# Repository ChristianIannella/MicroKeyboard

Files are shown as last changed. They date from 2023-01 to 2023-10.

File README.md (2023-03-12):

# MicroKeyboard

MicroKeyboard is a small customizable keyboard/mouse.

Based on [ArduinoMicro](https://store.arduino.cc/products/arduino-micro), it allows you to choose the function to be associated with each single key, including encoder and thumbstick.

MicroKeyboard is open-source and open-hardware but you can still decide to buy one already assembled on [Tindie](https://www.tindie.com/products/chris_maker_/microkeyboard/)

<picture><picture>

Thanks to PCBWay for sponsoring this project.

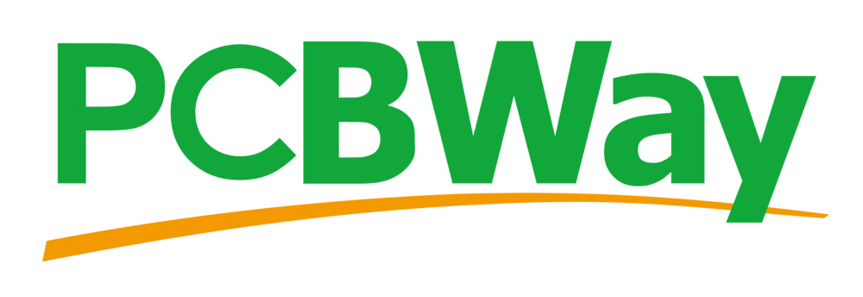
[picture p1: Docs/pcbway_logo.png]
PCBWay


[ITALIANO](https://github.com/ChristianIannella/MicroKeyboard/blob/main/ITALIANO.md)
  
[ENGLISH](https://github.com/ChristianIannella/MicroKeyboard/blob/main/ENGLISH.md)

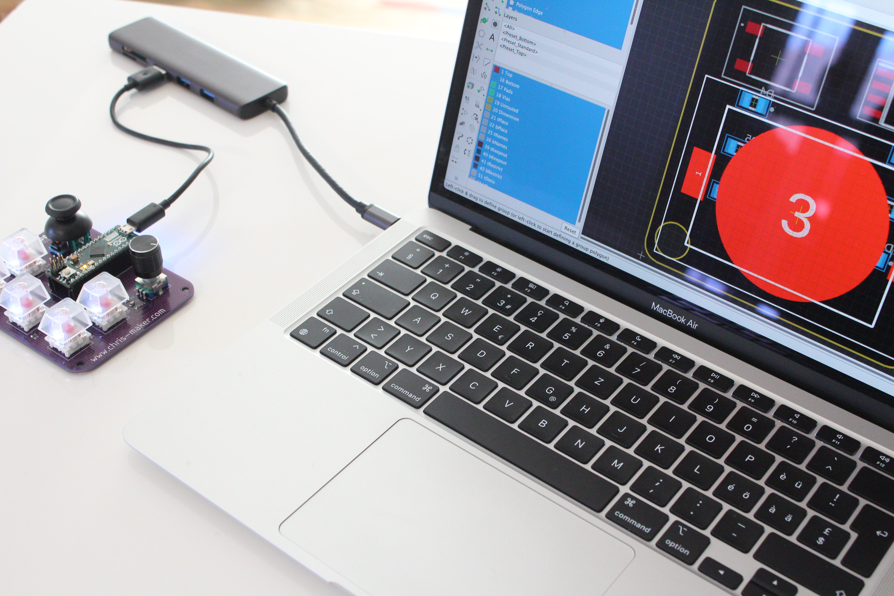
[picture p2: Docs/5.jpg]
MicroKeyboard


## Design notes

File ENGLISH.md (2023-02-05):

# MicroKeyboard

MicroKeyboard is a small customizable keyboard/mouse.

Based on [ArduinoMicro](https://store.arduino.cc/products/arduino-micro), it allows you to choose the function to be associated with each single key, including encoder and thumbstick.

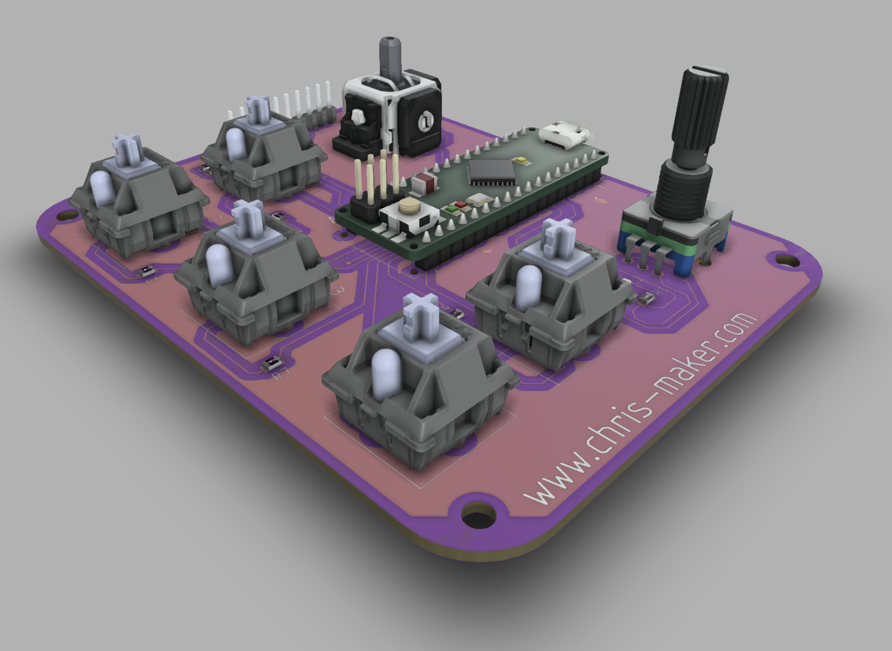
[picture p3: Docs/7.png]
MicroKeyboard


## PCB
  
On board the board you'll find a two-axis thumbstick with push button, a push button encoder, and five Cherry MX-style buttons. Each of the 5 buttons has a led connected to a `PWM` output of the micro in order to create an infinity of light effect.

Also you will find a connector with the remaining free pins of the micro including I2C and UART port.

The `SCL` and `SDA` pins are pulled-up from R8 and R9 (10k). If you want to interface a device via I2C or UART port that works at 3.3v you will need a level adapter.

Remember Arduino Micro works at 5v, if you decide to power the board from the external port remember that `VIN` must be between 7 and 12v!
  
For more details see [datasheet](https://store.arduino.cc/products/arduino-micro)

You can find Wiring diagram [here](https://github.com/ChristianIannella/MicroKeyboard/blob/main/Docs/Microkeyboard_schematic.png)  

## FIRMWARE  

There are some examples in the [Arduino](https://github.com/ChristianIannella/MicroKeyboard/tree/main/Arduino/Example_1) folder which you can use to inspire you to customize your MicroKeyboard.

You can choose from several [layout](https://github.com/ChristianIannella/MicroKeyboard/blob/main/Docs/Layout.txt)

Here is a list of all available functions [keycode](https://github.com/ChristianIannella/MicroKeyboard/blob/main/Docs/Keycode.txt)

In the examples two libraries are used, one for managing the encoder and one for simulating the mouse and keyboard.
  
  - [HID Project](https://github.com/NicoHood/HID) by [NicoHood](https://github.com/NicoHood)
  - [EncoderButton](https://github.com/Stutchbury/EncoderButton) by [Stutchbury](https://github.com/Stutchbury)
  
Visit these pages and you will discover how many things you can do with so few buttons.

In addition, it is possible to use the libraries made available by Arduino.cc

- [Keyboard](https://www.arduino.cc/reference/en/language/functions/usb/keyboard/)
- [Mouse](https://www.arduino.cc/reference/en/language/functions/usb/mouse/)

[BACK](https://github.com/ChristianIannella/MicroKeyboard)

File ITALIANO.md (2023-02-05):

# MicroKeyboard

MicroKeyboard è una piccola tastiera completamente customizzabile che in realtà racchiude anche un mouse.

Basata su [ArduinoMicro](https://store.arduino.cc/products/arduino-micro) permette di scegliere la funzione da associare ad ogni singolo tasto inclusi encoder e thumbstick.

MicroKeyboard

## PCB

A bordo della scheda troverai un thumbstick a due assi con pulsante, un encoder con pulsante e cinque pulsatti di tipo Cherry MX. Ognuno dei 5 pulsanti ha un led collegato a un uscita `PWM` del micro in modo da poter creare una infinità di giochi di luce.

Inoltre troverai un connettore con i rimanenti pin liberi del micro tra cui porta I2C e UART.
I pin `SCL` e `SDA` sono tenuti a pull-up da R8 e R9 (10k). Se vorrai interfacciare un dispositivo tramite porta I2C o UART che lavora a 3.3v avrai bisogno di un adattatore di livelli. 

Ricorda Arduino Micro lavora a 5v se invece decidi di alimentare la scheda dalla porta esterna ricorda che `VIN` deve essere compresa tra 7 e 12v!
  
Per maggiori dettagli consulta la scheda tecnica [qui](https://store.arduino.cc/products/arduino-micro)

Puoi trovare lo schema elettrico [qui](https://github.com/ChristianIannella/MicroKeyboard/blob/main/Docs/Microkeyboard_schematic.png)

## FIRMWARE  
  
Ci sono alcuni esempi nella cartella [Arduino](https://github.com/ChristianIannella/MicroKeyboard/tree/main/Arduino/Example_1) ai quali potrai ispirarti per customizzare la tua MicroKeyboard.  

E' possibile scegliere tra diversi [layout](https://github.com/ChristianIannella/MicroKeyboard/blob/main/Docs/Layout.txt) 

Ecco una lista di tutte le funzioni disponibili [keycode](https://github.com/ChristianIannella/MicroKeyboard/blob/main/Docs/Keycode.txt)
  
Negli esempi vengono utilizzate due librerie, una per la gestione dell'encoder e una per la simulazione di mouse e tastiera. 
  
  - [HID Project](https://github.com/NicoHood/HID) di [NicoHood](https://github.com/NicoHood)
  - [EncoderButton](https://github.com/Stutchbury/EncoderButton) di [Stutchbury](https://github.com/Stutchbury)
  
Visita queste pagine e scoprirai quante cose puoi fare con cosí pochi pulsanti.

In oltre è possibile sfruttare le librerie messe a disposizione da Arduino.cc 

- [Keyboard](https://www.arduino.cc/reference/en/language/functions/usb/keyboard/)
- [Mouse](https://www.arduino.cc/reference/en/language/functions/usb/mouse/)

[INDIETRO](https://github.com/ChristianIannella/MicroKeyboard)

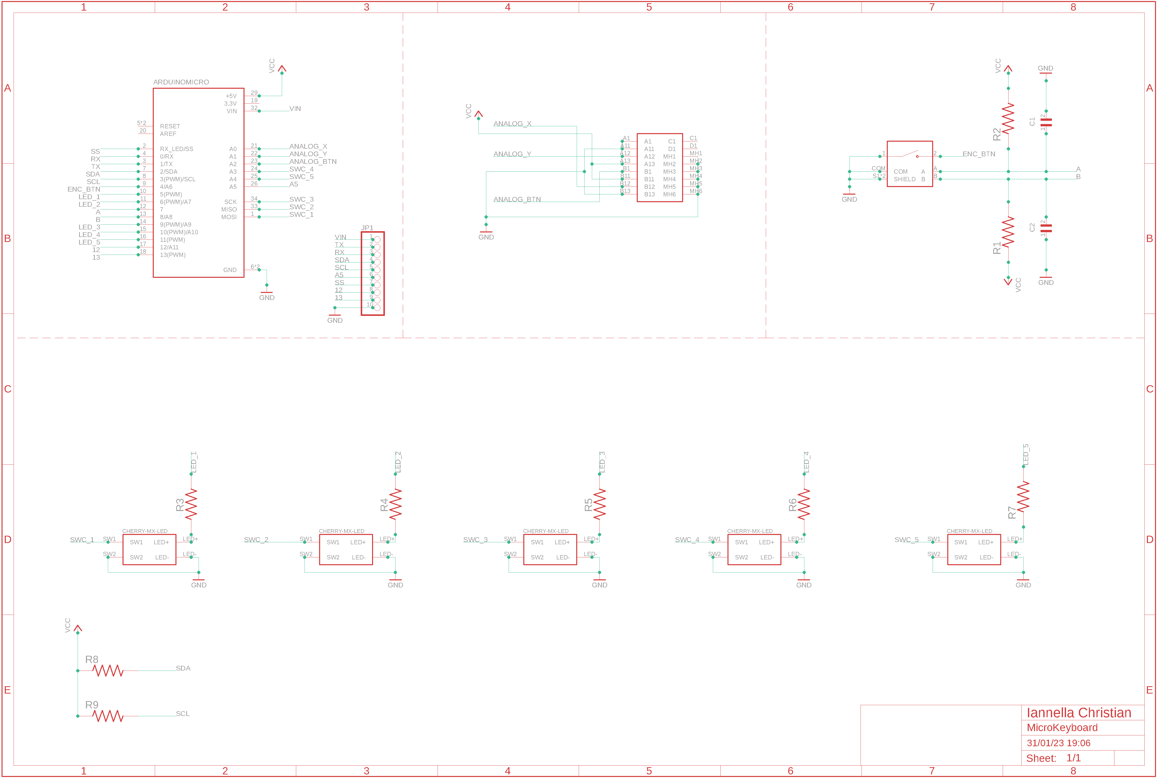
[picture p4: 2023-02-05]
Docs/Microkeyboard_schematic.png

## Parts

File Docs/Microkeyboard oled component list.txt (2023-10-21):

R1 1K
R2 1K
R3 1k
R4 1k
R6 4.7K
R7 4.7K
R8 10K
R9 10K

C1 0.01 uF
C2 0.01 uF

Display SSD1305 128x32

Pulsante Cherry MX

Led standard 3mm

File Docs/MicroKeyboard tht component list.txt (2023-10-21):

R1 1K
R2 1K
R3 1k
R4 1k
R5 1k
R6 4.7K
R7 4.7K
R8 10K
R9 10K

C1 0.01 uF
C2 0.01 uF

Pulsante Cherry MX
Led standard 3mm

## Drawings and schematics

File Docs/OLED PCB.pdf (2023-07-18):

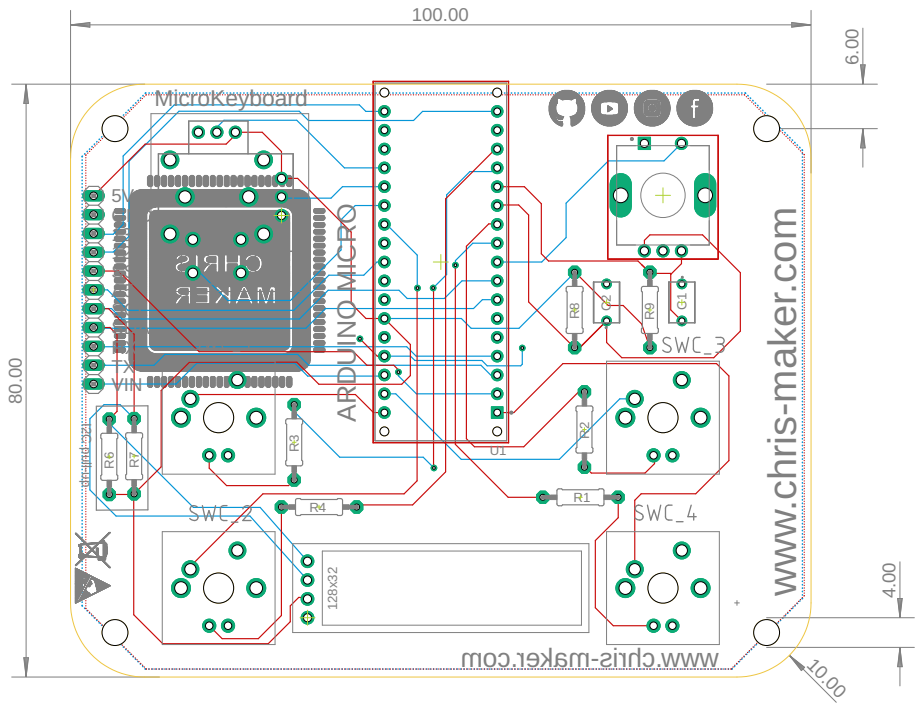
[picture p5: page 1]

moc.r eka m- sir hc. www ARDUINO MICRO w .chris-maker.com MicroKeyboard 128x32 80.00 100.00 10.04.00 6.00 GND 1312SSA5SCL SDA RXTXVIN I2C pull-up 5V S1 C2C1 R1R2 R3 R4 R6R7 R8 R9 U1

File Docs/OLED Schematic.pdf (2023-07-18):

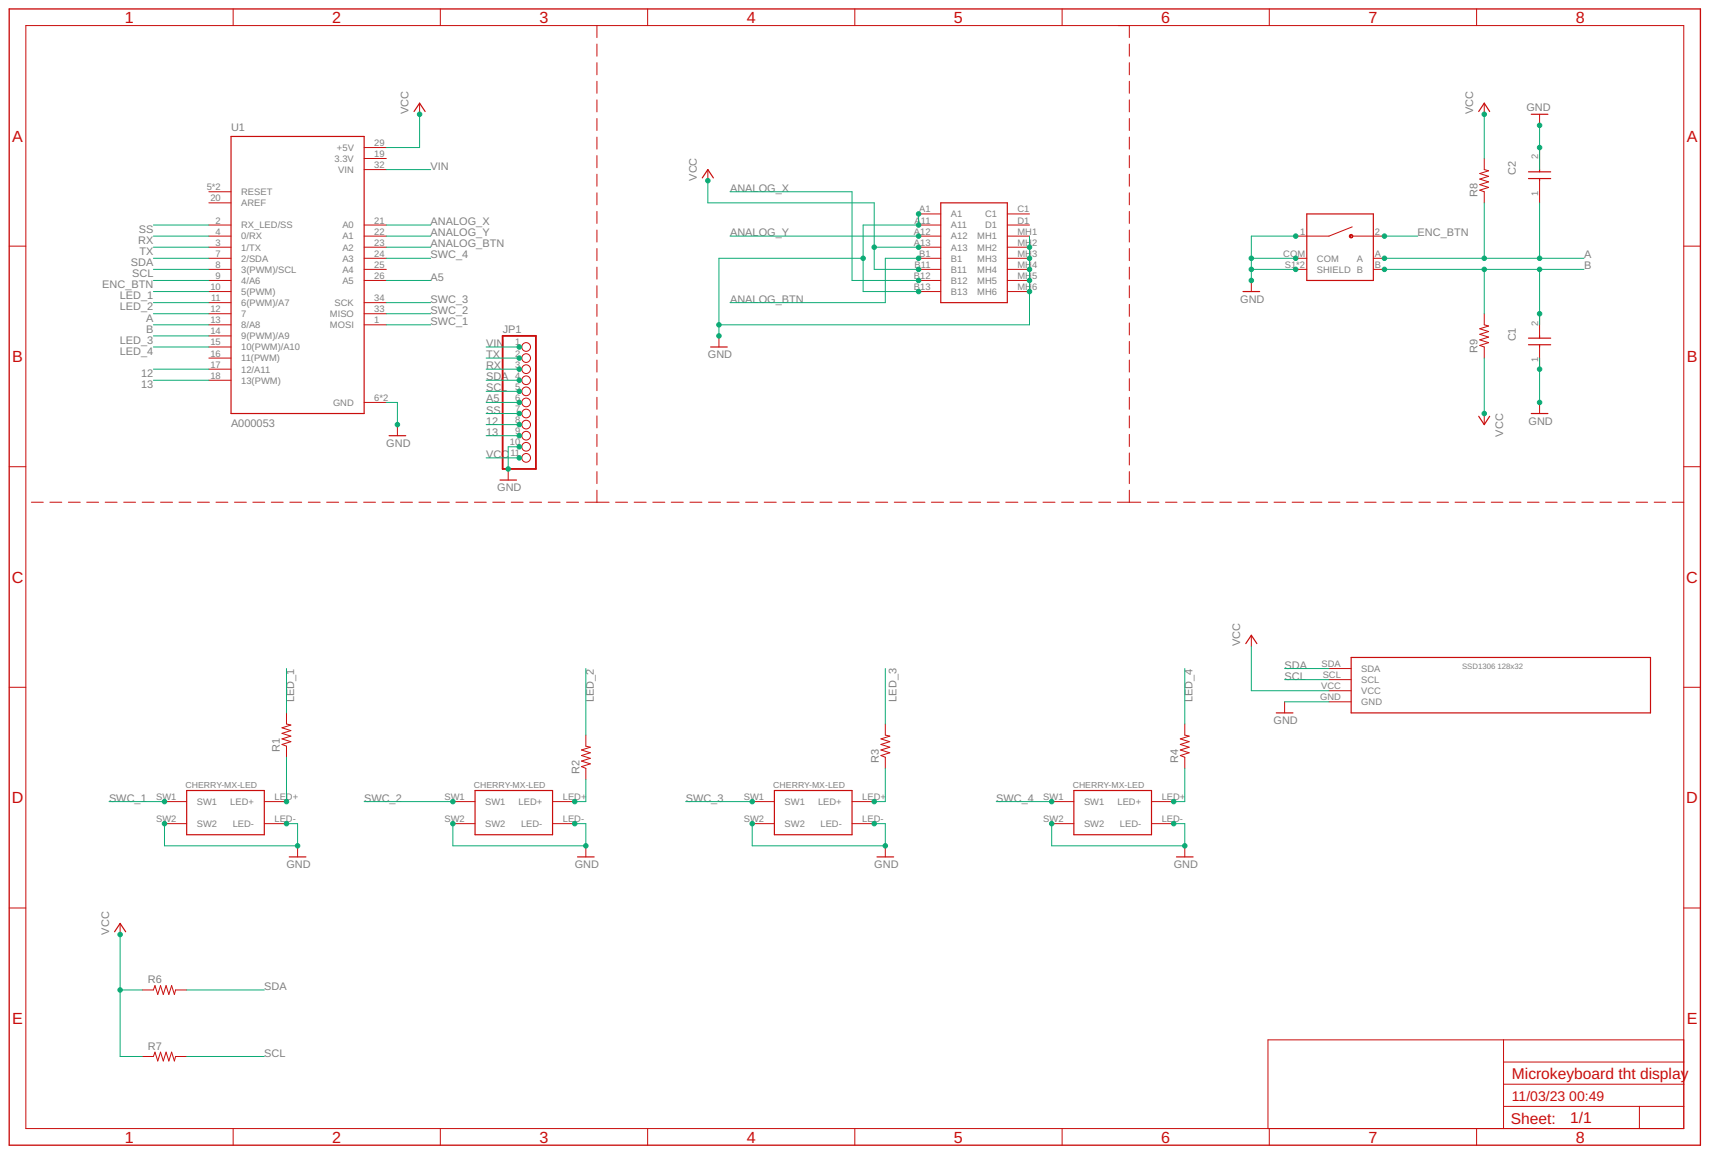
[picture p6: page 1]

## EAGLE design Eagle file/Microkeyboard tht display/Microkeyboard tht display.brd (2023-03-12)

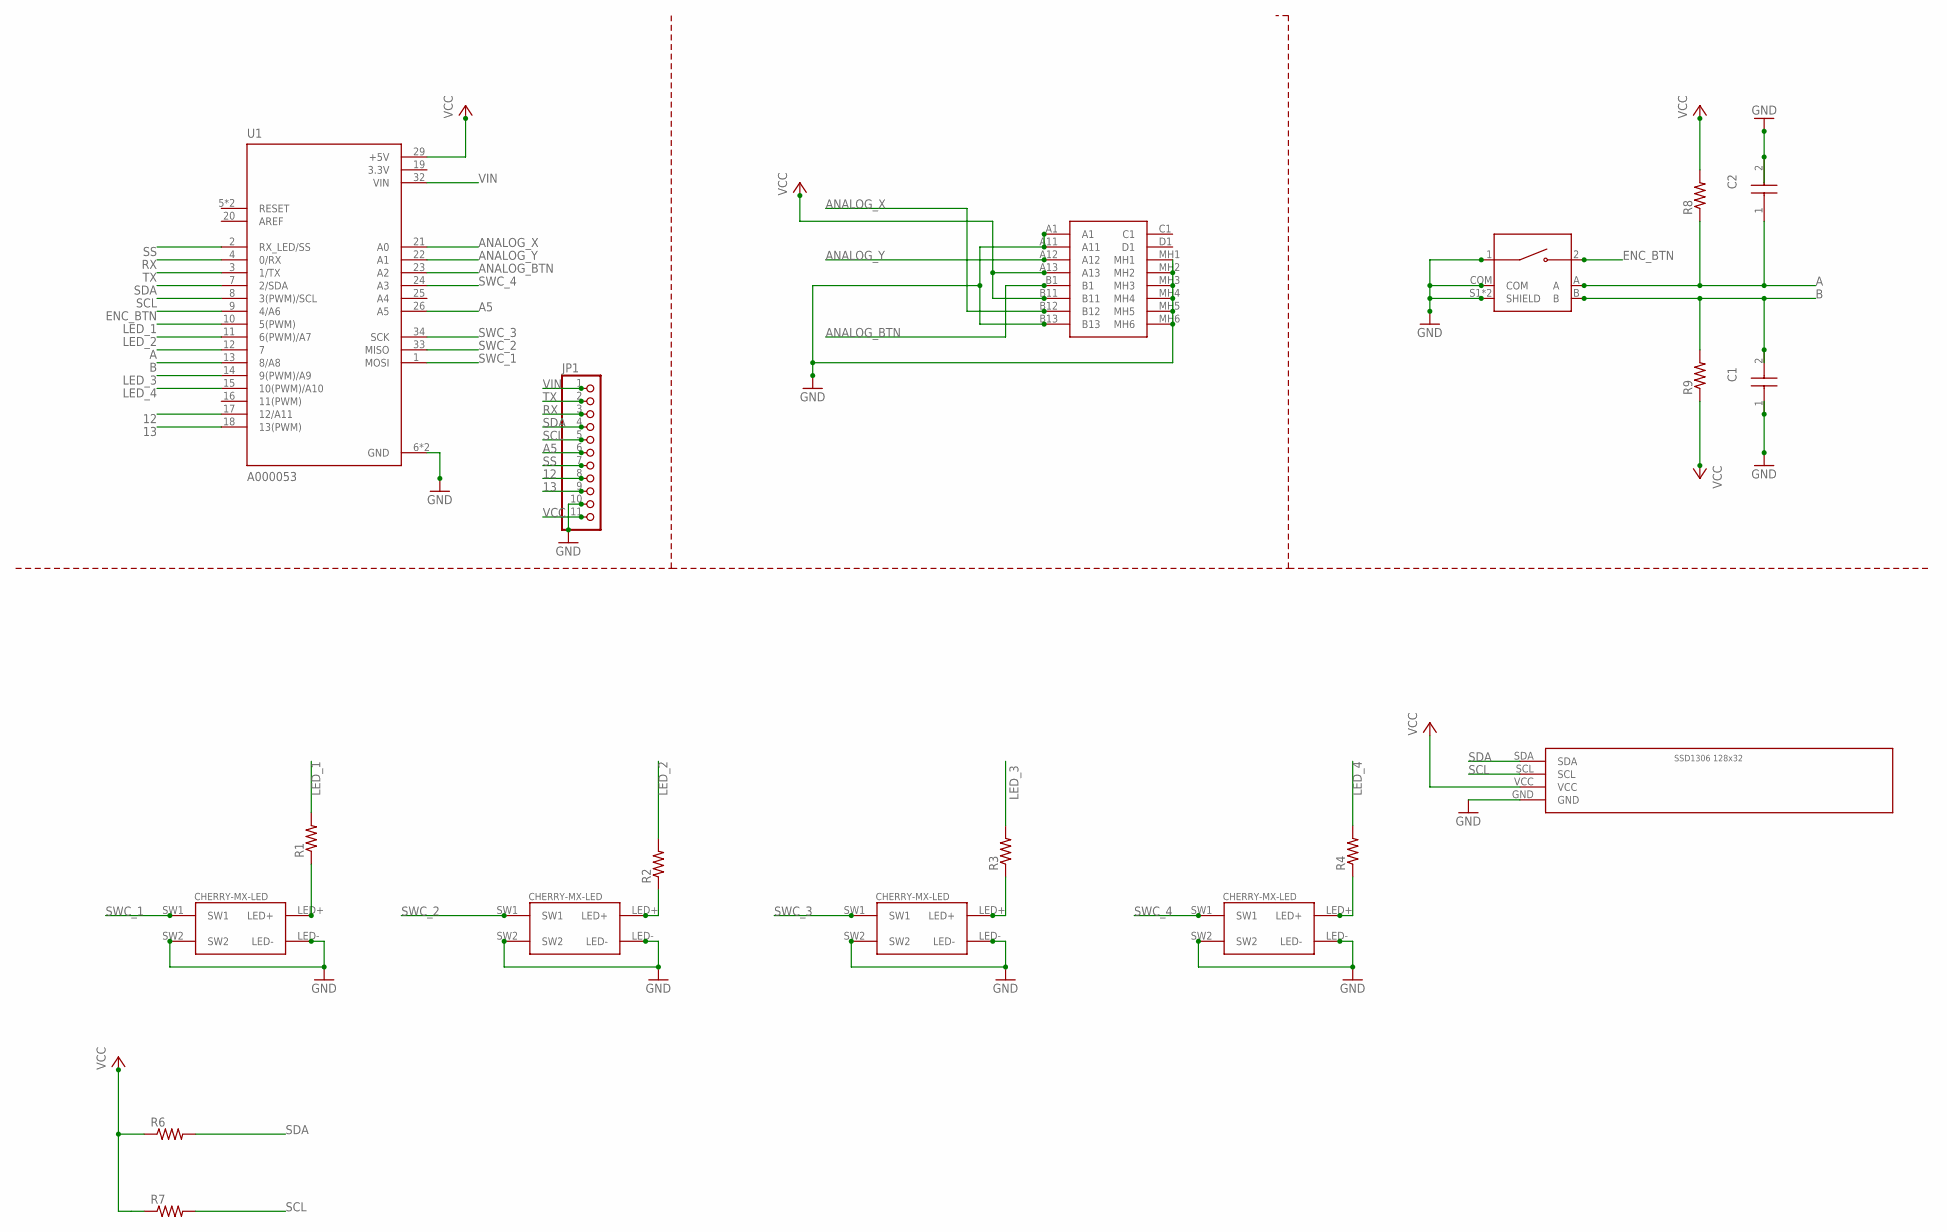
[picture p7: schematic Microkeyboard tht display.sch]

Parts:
C1, C2: FG26X7R2E104KNT06; FG26
JP1: PINHD-1X11; 1X11
MT1: PEC11R-4215F-S0024; XDCR_PEC11R-4215F-S0024
R1, R2, R3, R4, R6, R7, R8, R9: R-US_0207/10; 0207/10
S1: RKJXV122400R
SWC_1: SWC_1; CHERRY-MX-LED
U1: A000053; ARDUINO_A000053
U$1, U$2, U$5: CHERRY-MX-LED
U$3: SSD1306_128X32

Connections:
3.3V: U1.19 (3.3V)
12: JP1.8, U1.17 (12/A11)
13: JP1.9, U1.18 (13(PWM))
A: C2.1, MT1.A, R8.1, U1.12 (7)
A5: JP1.6, U1.26 (A5)
ANALOG_BTN: S1.B1, U1.23 (A2)
ANALOG_X: S1.B12, U1.21 (A0)
ANALOG_Y: S1.A12, U1.22 (A1)
B: C1.2, MT1.B, R9.2, U1.13 (8/A8)
ENC_BTN: MT1.2, U1.9 (4/A6)
GND: C1.1, C2.2, JP1.10, MT1.1, MT1.COM, MT1.S1 (SHIELD), MT1.S2 (SHIELD), S1.A1, S1.A11, S1.B13, S1.MH1, S1.MH2, S1.MH3, S1.MH4, S1.MH5, S1.MH6, SWC_1.LED-, SWC_1.SW2, U1.6 (GND), U1.31 (GND), U$1.LED-, U$1.SW2, U$2.LED-, U$2.SW2, U$3.GND, U$5.LED-, U$5.SW2
LED_1: R1.2, U1.10 (5(PWM))
LED_2: R2.2, U1.11 (6(PWM)/A7)
LED_3: R3.2, U1.14 (9(PWM)/A9)
LED_4: R4.2, U1.15 (10(PWM)/A10)
unnamed: R1.1, SWC_1.LED+
unnamed: R3.1, U$1.LED+
unnamed: R2.1, U$5.LED+
unnamed: R4.1, U$2.LED+
RX: JP1.3, U1.4 (0/RX)
SCL: JP1.5, R7.2, U1.8 (3(PWM)/SCL), U$3.SCL
SDA: JP1.4, R6.2, U1.7 (2/SDA), U$3.SDA
SS: JP1.7, U1.2 (RX_LED/SS)
SWC_1: SWC_1.SW1, U1.1 (MOSI)
SWC_2: U1.33 (MISO), U$5.SW1
SWC_3: U1.34 (SCK), U$1.SW1
SWC_4: U1.24 (A3), U$2.SW1
TX: JP1.2, U1.3 (1/TX)
VCC: JP1.11, R6.1, R7.1, R8.2, R9.1, S1.A13, S1.B11, U1.29 (+5V), U$3.VCC
VIN: JP1.1, U1.32 (VIN)

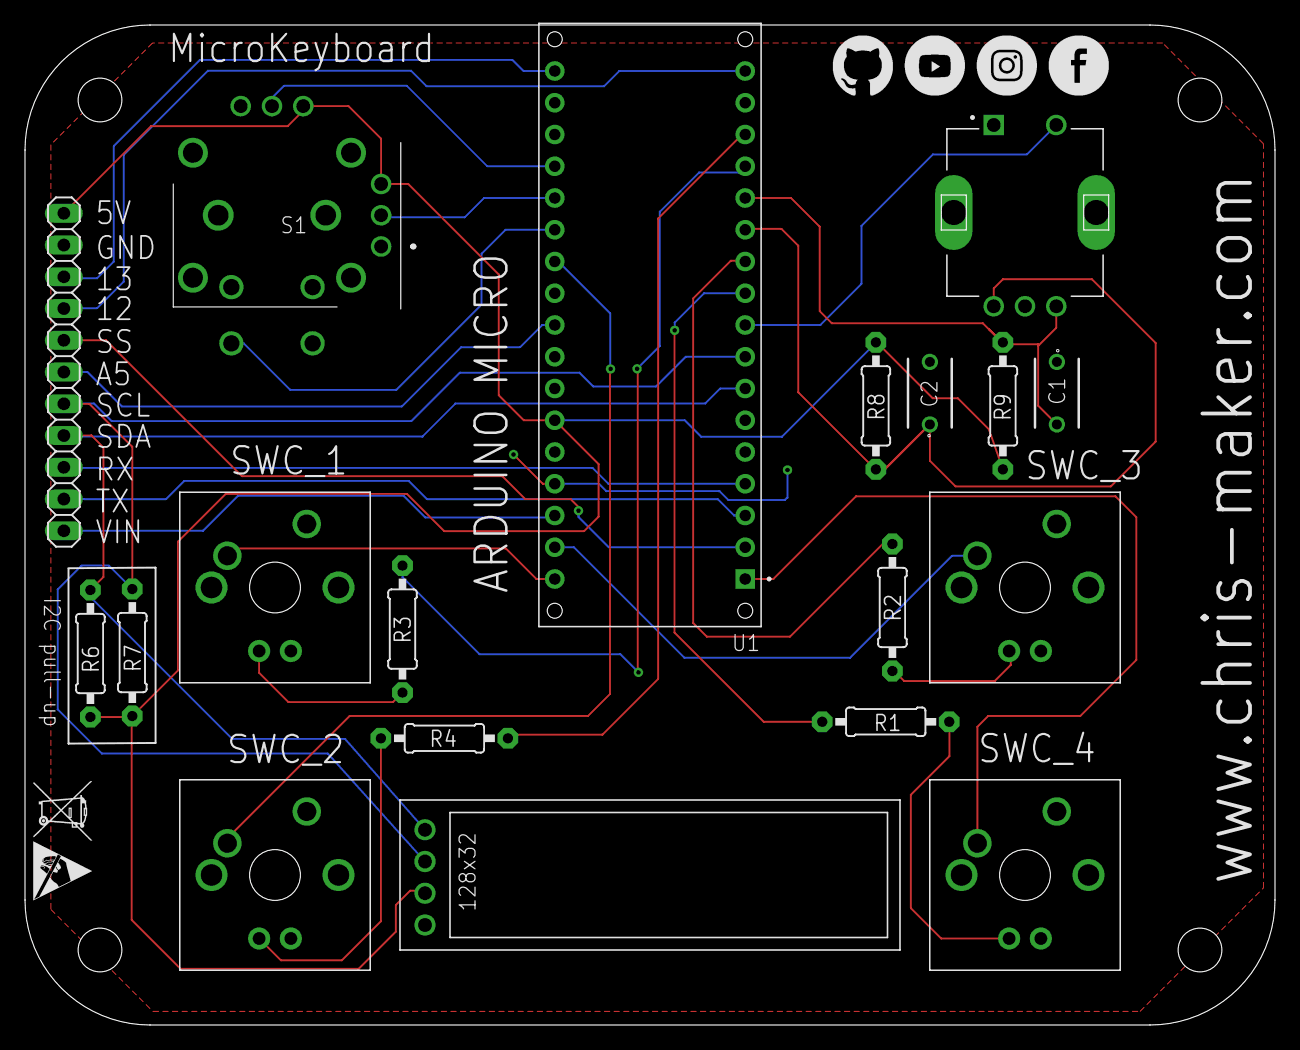
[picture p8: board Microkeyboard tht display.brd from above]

Board: 2 copper layers, 100.0 x 80.0 mm, 19 parts (0 on the bottom side), 29 nets.

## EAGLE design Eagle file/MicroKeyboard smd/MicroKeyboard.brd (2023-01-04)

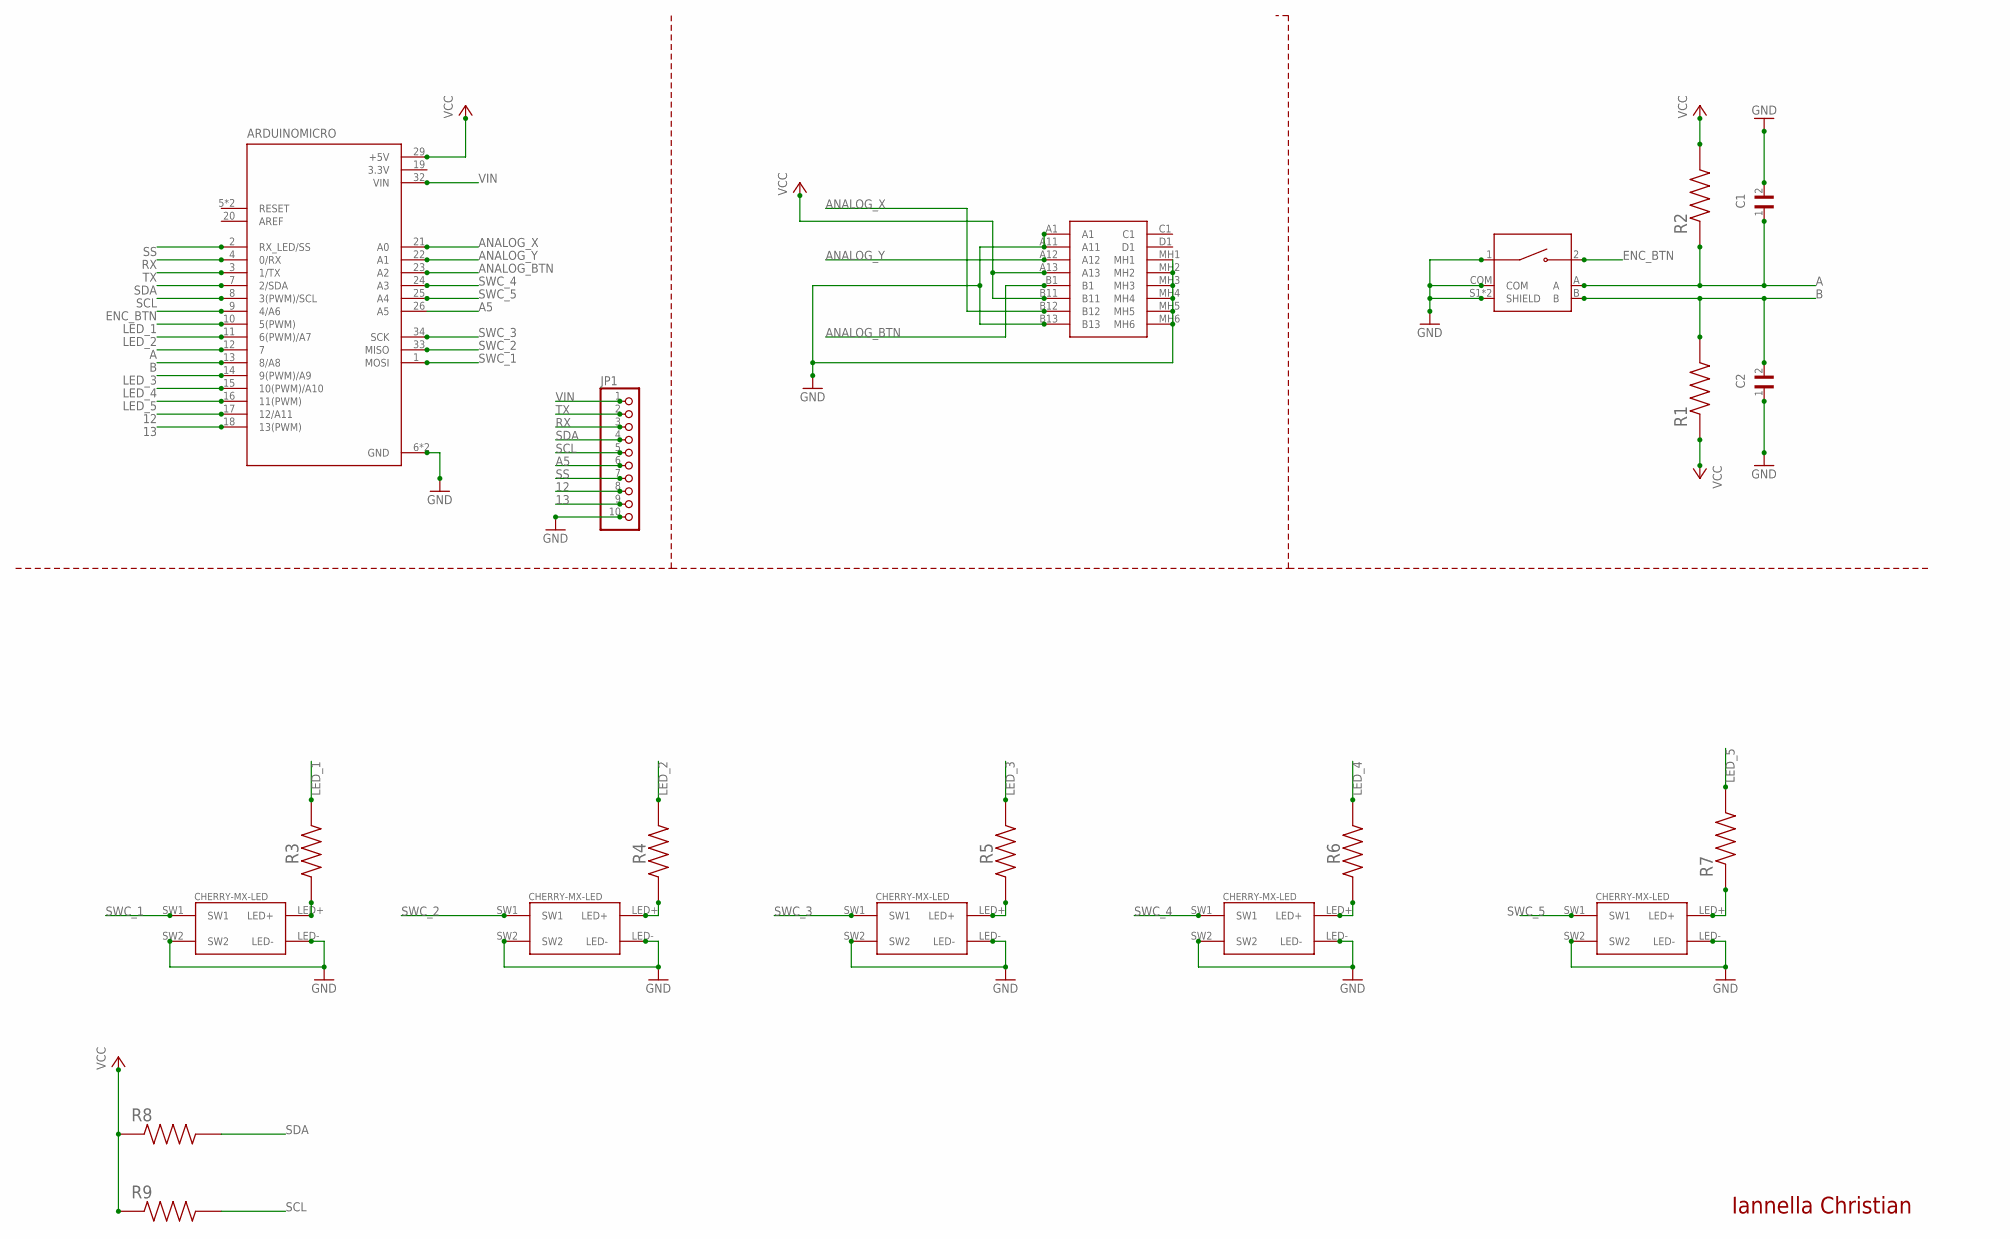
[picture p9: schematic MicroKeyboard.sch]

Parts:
ARDUINOMICRO: A000053; ARDUINO_A000053
C1, C2: 0805YC103J4T2A; CAPC2012X94N
JP1: PINHD-1X10; 1X10
MT1: PEC11R-4215F-S0024; XDCR_PEC11R-4215F-S0024
R1, R2, R3, R4, R5, R6, R7, R8, R9: RC0805FR-07330RL; RESC2012X60N
S1: RKJXV122400R
SWC_1: SWC_1; CHERRY-MX-LED
U$1, U$2, U$3, U$5: CHERRY-MX-LED

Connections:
3.3V: ARDUINOMICRO.19 (3.3V)
12: ARDUINOMICRO.17 (12/A11), JP1.8
13: ARDUINOMICRO.18 (13(PWM)), JP1.9
A: ARDUINOMICRO.12 (7), C1.1, MT1.A, R2.1
A5: ARDUINOMICRO.26 (A5), JP1.6
ANALOG_BTN: ARDUINOMICRO.23 (A2), S1.B1
ANALOG_X: ARDUINOMICRO.21 (A0), S1.B12
ANALOG_Y: ARDUINOMICRO.22 (A1), S1.A12
B: ARDUINOMICRO.13 (8/A8), C2.2, MT1.B, R1.2
ENC_BTN: ARDUINOMICRO.9 (4/A6), MT1.2
GND: ARDUINOMICRO.6 (GND), ARDUINOMICRO.31 (GND), C1.2, C2.1, JP1.10, MT1.1, MT1.COM, MT1.S1 (SHIELD), MT1.S2 (SHIELD), S1.A1, S1.A11, S1.B13, S1.MH1, S1.MH2, S1.MH3, S1.MH4, S1.MH5, S1.MH6, SWC_1.LED-, SWC_1.SW2, U$1.LED-, U$1.SW2, U$2.LED-, U$2.SW2, U$3.LED-, U$3.SW2, U$5.LED-, U$5.SW2
LED_1: ARDUINOMICRO.10 (5(PWM)), R3.2
LED_2: ARDUINOMICRO.11 (6(PWM)/A7), R4.2
LED_3: ARDUINOMICRO.14 (9(PWM)/A9), R5.2
LED_4: ARDUINOMICRO.15 (10(PWM)/A10), R6.2
LED_5: ARDUINOMICRO.16 (11(PWM)), R7.2
unnamed: R3.1, SWC_1.LED+
unnamed: R7.1, U$3.LED+
unnamed: R5.1, U$1.LED+
unnamed: R4.1, U$5.LED+
unnamed: R6.1, U$2.LED+
RX: ARDUINOMICRO.4 (0/RX), JP1.3
SCL: ARDUINOMICRO.8 (3(PWM)/SCL), JP1.5, R9.2
SDA: ARDUINOMICRO.7 (2/SDA), JP1.4, R8.2
SS: ARDUINOMICRO.2 (RX_LED/SS), JP1.7
SWC_1: ARDUINOMICRO.1 (MOSI), SWC_1.SW1
SWC_2: ARDUINOMICRO.33 (MISO), U$5.SW1
SWC_3: ARDUINOMICRO.34 (SCK), U$1.SW1
SWC_4: ARDUINOMICRO.24 (A3), U$2.SW1
SWC_5: ARDUINOMICRO.25 (A4), U$3.SW1
TX: ARDUINOMICRO.3 (1/TX), JP1.2
VCC: ARDUINOMICRO.29 (+5V), R1.1, R2.2, R8.1, R9.1, S1.A13, S1.B11
VIN: ARDUINOMICRO.32 (VIN), JP1.1

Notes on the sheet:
Iannella Christian

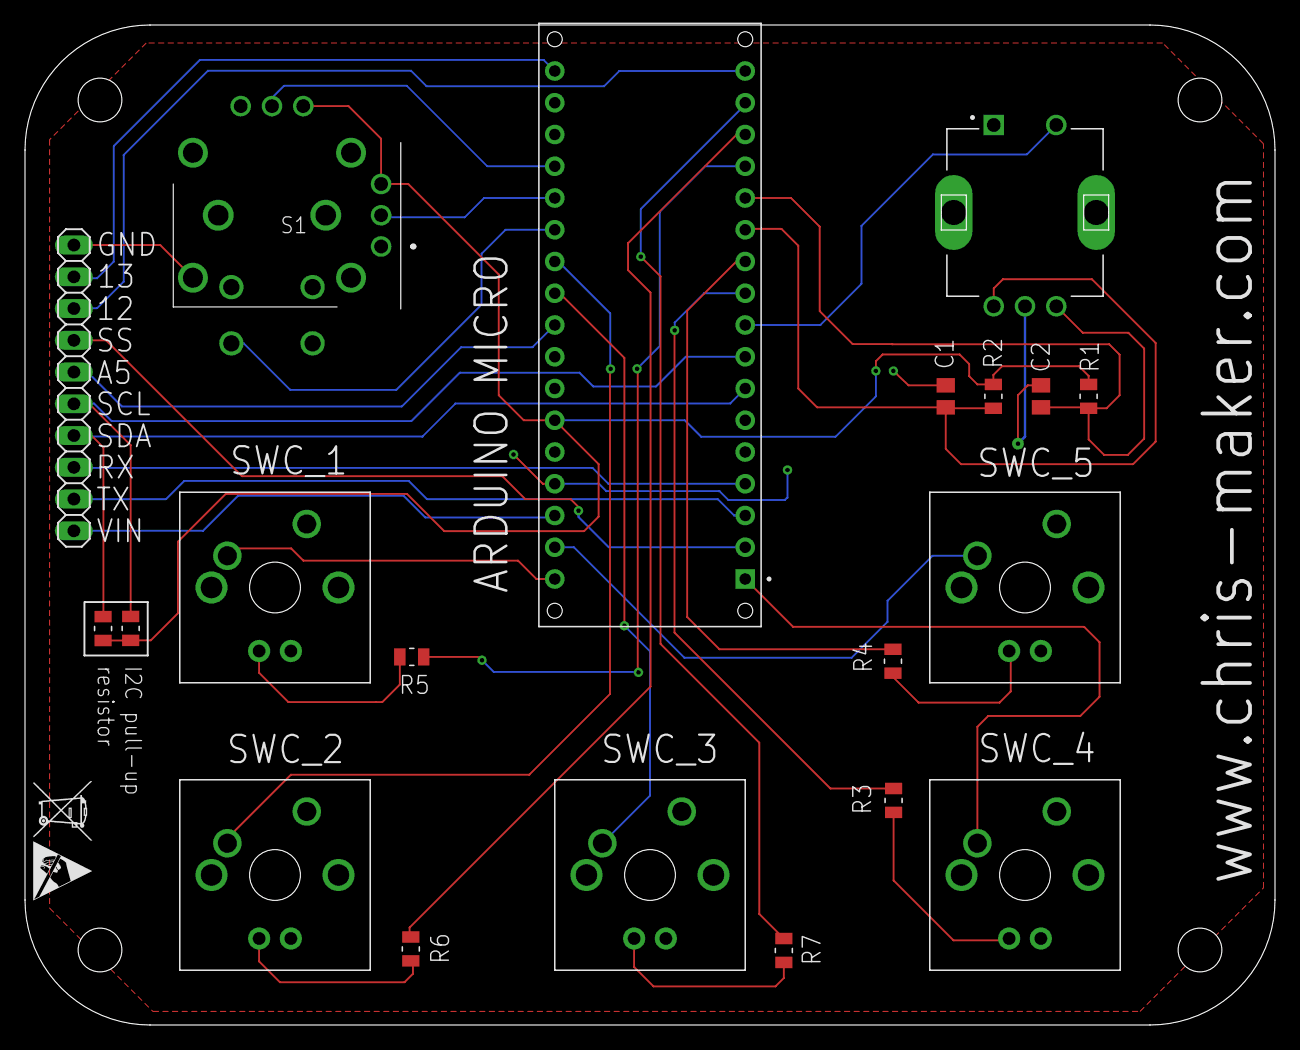
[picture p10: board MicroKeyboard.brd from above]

Board: 2 copper layers, 100.0 x 80.0 mm, 20 parts (0 on the bottom side), 32 nets.

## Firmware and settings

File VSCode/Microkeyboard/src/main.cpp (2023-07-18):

#define HID_CUSTOM_LAYOUT
#define LAYOUT_ITALIAN

#include <Arduino.h>
#include "HID-Project.h" 
#include <EncoderButton.h>

//#define DEBUG

#define ANALOG_X       18
#define ANALOG_Y       19
#define ANALOG_BTN     20
bool analog_btn_state = false;
const unsigned int mouse_delay = 20;
bool left_press = false;

#define ENC_A     7
#define ENC_B     8
#define ENC_BTN   4
bool zoom_scroll = false;
EncoderButton eb1(ENC_A, ENC_B, ENC_BTN);

static unsigned long previousMillis2 = 0;
static unsigned long previousMillis = 0; 
const long interval = 3;
int bg_brightness =  10;
int pushed_switch = 0;
bool increase_brightness = true;
bool decrease_brightness = false;

#define SWC_1     15
#define SWC_2     21
#define SWC_3     22
#define SWC_4     16
#define SWC_5     14

#define LED_1     9
#define LED_2     10
#define LED_3     11
#define LED_4     5
#define LED_5     6

bool swc_1_state = false;
bool swc_2_state = false;
bool swc_3_state = false;
bool swc_4_state = false;
bool swc_5_state = false;

void swc_1_pushed(){ // your password

  #ifdef DEBUG
    Serial.println("1 pushed");
  #endif

  pushed_switch = LED_1;
  Keyboard.println("your_password");
}

void swc_2_pushed(){ // email address

  #ifdef DEBUG
    Serial.println("2 pushed");
  #endif

  pushed_switch = LED_2;
  Keyboard.print("your_mail");
}

void swc_3_pushed(){ // clic cancel

  #ifdef DEBUG
    Serial.println("3 pushed");
  #endif

  pushed_switch = LED_3;
  BootKeyboard.write(KEY_DELETE);
}

void swc_4_pushed(){ // clic mouse left button

  #ifdef DEBUG
    Serial.println("4 pushed");
  #endif

  pushed_switch = LED_4;
  AbsoluteMouse.click(MOUSE_LEFT);
}

void swc_5_pushed(){ // press/release mouse left button

  #ifdef DEBUG
    Serial.println("5 pushed");
  #endif

  pushed_switch = LED_5;

  if (left_press == false) {
    AbsoluteMouse.press(MOUSE_LEFT);
    digitalWrite(LED_BUILTIN, HIGH);
    left_press = true;
  }
  else if(left_press == true){
    AbsoluteMouse.release(MOUSE_LEFT);
    digitalWrite(LED_BUILTIN, LOW);
    left_press = false;
  }
}

void analog_btn_pushed(){

  #ifdef DEBUG
    Serial.println("Analog pushed");
  #endif

  AbsoluteMouse.click(MOUSE_RIGHT);

}

void onEb1Clicked(EncoderButton& eb) {

  #ifdef DEBUG
    Serial.println("Encoder pushed");
  #endif

  if (eb.clickCount()== 1){
    zoom_scroll = !zoom_scroll;
    
  }
  else if (eb.clickCount()== 2){
    //pass 
  }
}

void onEb1Encoder(EncoderButton& eb) {

  if (eb.increment() == 1){

    #ifdef DEBUG
      Serial.println("Encoder +");
    #endif

    if (zoom_scroll == false){
      Mouse.move(0,0,1); 
    }
    else{
      Keyboard.press(KEYPAD_ADD); 
      delay(50);
      Keyboard.releaseAll(); 
    }
  }
  else if (eb.increment() == -1){

    #ifdef DEBUG
      Serial.println("Encoder -");
    #endif

    if (zoom_scroll == false){
      Mouse.move(0,0,-1); 
    }
    else {
      Keyboard.press(KEYPAD_SUBTRACT); 
      delay(50);
      Keyboard.releaseAll(); 
    }
  }
  //eb.position();
}

void check_button_press(){

  if (swc_1_state == false){
    if (digitalRead(SWC_1)==LOW){
      delay(20);
      if (digitalRead(SWC_1)==LOW){
        swc_1_state = true;
        swc_1_pushed(); 
      }
    }    
  }
  if (digitalRead(SWC_1)==HIGH){
    swc_1_state = false;
  }

    if (swc_2_state == false){
    if (digitalRead(SWC_2)==LOW){
      delay(20);
      if (digitalRead(SWC_2)==LOW){
        swc_2_state = true;
        swc_2_pushed(); 
      }
    }    
  }
  if (digitalRead(SWC_2)==HIGH){
    swc_2_state = false;
  }

  if (swc_3_state == false){
    if (digitalRead(SWC_3)==LOW){
      delay(20);
      if (digitalRead(SWC_3)==LOW){
        swc_3_state = true;
        swc_3_pushed(); 
      }
    }    
  }
  if (digitalRead(SWC_3)==HIGH){
    swc_3_state = false;
  }

  if (swc_4_state == false){
    if (digitalRead(SWC_4)==LOW){
      delay(20);
      if (digitalRead(SWC_4)==LOW){
        swc_4_state = true;
        swc_4_pushed(); 
      }
    }    
  }
  if (digitalRead(SWC_4)==HIGH){
    swc_4_state = false;
  }

  if (swc_5_state == false){
    if (digitalRead(SWC_5)==LOW){
      delay(20);
      if (digitalRead(SWC_5)==LOW){
        swc_5_state = true;
        swc_5_pushed(); 
      }
    }    
  }
  if (digitalRead(SWC_5)==HIGH){
    swc_5_state = false;
  }

  if (analog_btn_state == false){
    if (digitalRead(ANALOG_BTN)==LOW){
      delay(20);
      if (digitalRead(ANALOG_BTN)==LOW){
        analog_btn_state = true;
        analog_btn_pushed(); 
      }
    }    
  }
  if (digitalRead(ANALOG_BTN)==HIGH){
    analog_btn_state = false;
  }

}

void led_effect(){

  if (pushed_switch != 0) {

    if (increase_brightness == true){

      if(bg_brightness <= 240) {
        bg_brightness += 10;
        analogWrite(pushed_switch, bg_brightness);
      }
      else if(bg_brightness > 240){
        increase_brightness = false;
        decrease_brightness = true;
      }
    }
    if(decrease_brightness == true) {
      if(bg_brightness > 10) {
        bg_brightness -= 10;
        analogWrite(pushed_switch, bg_brightness);
      }
      else if(bg_brightness == 10){
        increase_brightness = true;
        decrease_brightness = false;
        pushed_switch = 0;
      }
    }
  }
}

void mouse_move(int x, int y){

  int delta_x = 0;
  int delta_y = 0;

  if (x>600){
    int i = map(x,600,1024,1,20);
    delta_x=i; 
  } 

  else if (x<400){
    int i = map(x,400,0,1,20);
    delta_x=-i; 
  } 
  
  if (y>600) {
    int l = map(y,600,1024,1,20);
    delta_y=-l; 
  } 

  else if (y<400){
    int l = map(y,400,0,1,20);
    delta_y=l;  
  } 
  
  Mouse.move(delta_x,delta_y,0); 

  }

void setup() {

  #ifdef DEBUG
    Serial.begin(9600);
  #endif

  pinMode(LED_BUILTIN, OUTPUT);

  pinMode(SWC_1, INPUT_PULLUP);
  pinMode(SWC_2, INPUT_PULLUP);
  pinMode(SWC_3, INPUT_PULLUP);
  pinMode(SWC_4, INPUT_PULLUP);
  pinMode(SWC_5, INPUT_PULLUP);

  pinMode(ANALOG_BTN, INPUT_PULLUP);

  pinMode(LED_1, OUTPUT);
  pinMode(LED_2, OUTPUT);
  pinMode(LED_3, OUTPUT);
  pinMode(LED_4, OUTPUT);
  pinMode(LED_5, OUTPUT);
  
  for (int i = 0; i <= 250; i+=10) {
    analogWrite(LED_1,i);
    analogWrite(LED_2,i);
    analogWrite(LED_3,i);
    analogWrite(LED_4,i);
    analogWrite(LED_5,i);
    delay(7);
  }
  for (int i = 250; i >= bg_brightness; i-=10) {
    analogWrite(LED_1,i);
    analogWrite(LED_2,i);
    analogWrite(LED_3,i);
    analogWrite(LED_4,i);
    analogWrite(LED_5,i);
    delay(7);
  }
  
  Keyboard.begin();
  Mouse.begin();
  //Consumer.begin();
  //Gamepad.begin();

  eb1.setClickHandler(onEb1Clicked);
  eb1.setEncoderHandler(onEb1Encoder);

}

void loop() {

  unsigned long currentMillis = millis();

  eb1.update();

  check_button_press();

  if (currentMillis - previousMillis >= interval) {
    previousMillis = currentMillis;
    led_effect();
  } 

   int x = analogRead(ANALOG_X);
   int y = analogRead(ANALOG_Y);
   
   if (previousMillis2 > millis()) previousMillis2 = millis(); 

   if (millis() - previousMillis2 >= mouse_delay) 
    {
    mouse_move(x,y);
    previousMillis2 = millis();
    }
} 
